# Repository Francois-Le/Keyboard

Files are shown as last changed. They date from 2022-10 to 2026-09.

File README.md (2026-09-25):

Complete custom keyboard with pcb design, 3D printable casing and firmware for a raspberry pi pico. Uses kailh low profile switches.

*Warning:* PCB_v2 may have some design mistake, I can't remember if I fixed them.

The firmware in `code/arduino_keyboard` provides HID keyboard output and an
optional binary USB serial trace. See its README for Arduino Mbed Pico build
instructions.

Open `code/remote/index.html` in desktop Chrome or Edge for the Web Serial
debugger: a vertical input/decision/HID timeline with queue inspection. It works
as a local file or a hosted HTTPS page; **Demo trace** works without hardware.
The remote README describes the protocol, capture export/import and development.

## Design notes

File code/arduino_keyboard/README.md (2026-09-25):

# Keyboard firmware and serial tracing

Target: Raspberry Pi Pico, **Arduino Mbed OS RP2040 Boards** (`arduino:mbed_rp2040:pico`).
The firmware uses the Mbed core's pluggable USB HID and CDC modules on the same
USB connection. It is not intended for the unrelated Earle Philhower RP2040 core.

Build with Arduino IDE or Arduino CLI (Mbed RP2040 core 4.6.0):

```powershell
arduino-cli core install arduino:mbed_rp2040@4.6.0
arduino-cli compile --fqbn arduino:mbed_rp2040:pico code\arduino_keyboard
```

Upload using the Pico's usual Arduino/BOOTSEL workflow. Opening the serial
debugger is optional: HID typing continues without it. Open
`code\remote\index.html` in desktop Chrome or Edge, select the keyboard's serial
port and close any other serial monitor first.

## Trace behavior

`REMOTE_TRACE` in `config.h` is enabled by default. It emits the KBT1 binary
protocol documented in `code\remote\README.md`. The interface is output-only:
there are no parameter-setting commands yet. Do not open it at 1200 baud, which
the Mbed core reserves for entering the bootloader.

- Events cover sampled switch changes, debounce/tap/overlap waits and decisions,
  queue removal, layer masks, I2C recovery attempts and exact HID reports.
- Input timestamps describe software observations, not exact electrical edges.
  HID success is the return value of the USB submission API, not proof that the
  OS/application received a key. A single `HID_OUTPUT` trace frame combines the
  keyboard and media reports, keeping both submission results and durations.
  The actual two USB HID reports are unchanged.
- A 24 KiB, fixed-size ring decouples instrumentation from USB. The loop makes
  at most four nonblocking `send_nb()` attempts per service call, preserving
  partially sent frames. It never waits for a debugger or a slow reader.
- Collection starts when CDC DTR is asserted. Closing the port discards pending
  telemetry. This is live capture, not a persistent pre-connection recorder.
- Reconnect starts a new stream with metadata and a queue checkpoint. Complete
  checkpoints are also attempted every two seconds; insufficient buffer space
  defers the whole checkpoint until space is available.
- Metadata includes the names in `s_layerNames` in `keyConfig.h`, indexed by
  the same masks as `s_keyMaps`. Keep these aligned when changing key maps.
  Names are limited to 24 printable ASCII characters and checked at compile
  time. Metadata and queue records are reserved as one complete batch.
- Trace overflow drops new trace frames, increments the sequence and exposes a
  loss counter. The browser marks reconstruction unknown until a checkpoint.
  This is separate from the existing processing queue's overflow: that behavior
  is unchanged, but an explicit `QUEUE_OVERFLOW` marker now exposes it.
- The UI reconstructs the logical processing queue, not a dump of unused slots
  or deletion markers. Entries retain physical slot numbers and stable IDs.
- Timestamps extend the 32-bit microsecond clock in the main loop. As with other
  polling clock extensions, an entire clock wrap spent blocked (about 71 minutes)
  cannot be recovered. Existing HID sends, I2C operations and tap delays retain
  their existing behavior; the new CDC transmitter does not add blocking waits.

Legacy `DEBUG_LOG`, `I2C_RESET_LOG` and `PERF_LOG` text modes cannot be mixed with
the binary stream. Disable `REMOTE_TRACE` before enabling them.

## Host-side trace checks

With Clang and a working C++ standard library installed:

```powershell
clang++ -std=c++17 -Icode\tests\stubs code\tests\trace_test.cpp -o trace-test.exe
.\trace-test.exe
```

The test compiles the actual trace implementation against a USB stub, including
short/zero writes, CRC framing, timestamp wrap, queue-slot wrap, trace loss and
reconnect. An optional filename argument writes a binary capture for exercising
the browser decoder. This does not replace physical HID + CDC enumeration,
unplug/replug and typing checks on the Pico.

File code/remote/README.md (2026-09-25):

# Keyboard Trace Timeline

Standalone local Web Serial viewer for the custom keyboard KBT1 trace stream. Open `index.html` by double-clicking it, or host the same file over HTTPS. There are no runtime network dependencies, module imports, service workers, framework bundles or telemetry. Only the display-layout preference is saved in browser storage; captures are not stored automatically.

## Build and test

```powershell
cd code\remote
node build.mjs
node --test
```

`src\trace.js`, `src\app.js`, and `src\styles.css` are the classic sources. `index.html` is the tracked generated artifact.

## Connect

1. Use Edge or Chrome with Web Serial support.
2. Open `index.html` locally or from HTTPS.
3. Click **Connect keyboard** and select the serial device.
4. The app opens at `115200` baud and sets DTR `true`.

The app never uses 1200-baud reset and never writes commands to the device. If no valid `HELLO` arrives shortly after opening, the UI warns about wrong/old firmware or port selection. Use **Demo trace** without hardware. Import/demo are disabled while live capture is active to avoid mixing sources.

Trace data can reveal typed keys. Exports are JSON and stay local unless you share them.

The app fits the viewport; the timeline and details panel scroll independently.
The **CHECKPOINT** category contains HELLO metadata and successful queue
snapshots and is unchecked by default. Hidden checkpoints are still processed
and exported, so queue reconstruction remains accurate. Checkpoint errors and
trace-loss warnings stay in **INTERNAL**.
**INTERNAL** shows debounce cancellations, overlap removals and layer changes,
plus faults such as I2C resets, queue overflow and stream errors.
Routine waits, processing, tap/hold decisions, queue removals and connection
boundaries are in **DETAILS**, also unchecked by default. Filtering affects only
display: all events still update the model and remain available in exports.
Older imported captures are reclassified into these categories automatically.
Layer changes use names supplied by firmware metadata, e.g. **Layer changed:
Accent 2**, with the numeric mask still available in the inspector. The name
table is indexed by the effective key-map mask, not by individual held layer
keys: masks 6 and 7 both select Accent 2. Names stay attached to their original
events across reconnects and capture export/import. Older firmware/captures or
incomplete/lost metadata display the numeric mask instead of guessing.
Reflash the firmware to enable layer-name metadata.
All timeline rows have one-line summaries: event/action, relevant IDs or layer,
and time. Checkpoints show the stream ID or pending queue count. Click a row for timestamps, report
bytes, submission results, transitions and queue state. Visible row/column
numbers start at 1; raw protocol coordinates start at 0. Output summaries show
the currently reported pressed keys using the selected **Layout**:
**English (US QWERTY)** or **French (France AZERTY)** (traditional PC layout).
French labels include A/Q, Z/W, M and punctuation/accent keys, and AltGr.
This changes the viewer only, not the firmware or the computer's keyboard layout.
Output shows the translated symbol first, followed by the physical combination
in gray: `OUTPUT { (AltGr, ')`. Shift and French AltGr (including Windows
Ctrl+Alt) are interpreted. The parentheses retain unmodified key labels.
Letters assume Caps Lock off; keypad keys retain their names because Num Lock
is not captured. Shortcuts are labeled `Shortcut`, dead keys `Dead`, and
unsupported modifier levels `Unmapped`. This is a preview of each held key,
not an ordered text stream or confirmation of host input. Dead-key/IME
composition is not inferred. Failed submissions remain visibly marked.

Changing Layout immediately relabels retained/imported events and their inspector
headings. Exported summaries use the selected layout while raw HID bytes remain
unchanged; importing uses your current display preference. English is the initial
default. The selection is remembered for the current site/local-file context when
browser storage is available; otherwise a session-only notice is shown.

### Layout library choice

No new runtime dependency is needed for these two layouts.
[Keyboard Map API](https://wicg.github.io/keyboard-map/#h-keyboard-getlayoutmap)
only exposes unmodified labels, not the Shift/AltGr levels required here.
[simple-keyboard-layouts](https://github.com/hodgef/simple-keyboard-layouts)
provides onscreen keyboard rows rather than a HID/modifier decoder;
[native-keymap](https://github.com/microsoft/node-native-keymap) requires native
Node bindings and cannot run in a standalone browser file.
[hid-io/layouts](https://github.com/hid-io/layouts) is a useful data source if
more layouts are added, but is not a browser text-input engine.

The explicit French levels follow the traditional Windows
[KBDFR shift states](https://kbdlayout.info/KBDfr/shiftstates).
Keeping the small tables in the bundle works offline and permits deterministic
replay using the selected layout, independent of the viewer's current OS layout.

Update the firmware to get one combined keyboard/media trace event per output.
The viewer also accepts the older individual type-5 reports and saved captures.

## KBT1 frame format

Every frame is exactly 48 bytes:

| Offset | Field |
| --- | --- |
| 0..3 | ASCII magic `KBT1` |
| 4 | type |
| 5..7 | reserved, must be zero |
| 8..11 | sequence `uint32LE`, increments for every attempted frame including drops |
| 12..19 | extended device timestamp, microseconds, `uint64LE` |
| 20..45 | 26-byte payload, zero padded |
| 46..47 | CRC16-CCITT-FALSE `uint16LE`, polynomial `0x1021`, init `0xffff`, over bytes 0..45 |

Unsupported `KBTx` versions, CRC errors, garbage, invalid reserved bytes, unknown types, sequence gaps, and malformed payload values are surfaced as timeline errors. Parser errors immediately invalidate queue state.

## Payloads

Offsets below are relative to payload byte 20.

### `1 HELLO`

`boardVersion u8@0`, `rows u8@1`, `cols u8@2`, `overlapEnabled u8@3` (`0/1`), `debounceUs u32@4`, `overlapUs u32@8`, `maxHoldUs u32@12`, `keyPressMs u32@16`, `streamId u32@20`, `layerCount u16@24`.

Sent on start and at periodic 2s checkpoints. Repeated `HELLO` does not erase the prior timeline and does not establish queue contents; only a complete snapshot does.
`layerCount` is zero in older firmware. When nonzero, HELLO is followed by that
many type-13 records (masks 0 through `layerCount - 1`) before SNAPSHOT_BEGIN.
The name table is published only when all records arrive in order without gaps.
The individual name records do not add timeline rows.

### `2 INPUT` and `7 SNAPSHOT_ENTRY`

`id u32@0`, `sampleMicros32 u32@4`, `row u8@8`, `col u8@9`, `pressed u8@10` (`0/1`), `queue slot u8@11`.

Rows/cols are checked after `HELLO`. Queue order is ring order from checkpoints, including wrap (`254,255,0`), not numeric sort.

### `3 REMOVE`

`id u32@0`, `reason u8@4`, `slot u8@5`.

Reasons: `1 processed`, `2 debounce`, `3 tap`, `4 overlap`. Removal must match both id and slot when queue is known.

### `4 DECISION`

`primaryID u32@0`, `relatedID u32@4`, `action u8@8`, `layerMask u8@9`, `interveningCount u8@10`.

Actions: `1 debounceWait`, `2 debounceCancel`, `3 overlapWait`, `4 overlapTap`, `5 tapWait`, `6 tap`, `7 hold(no tap)`, `8 process`, `9 layer`.

### `5 HID`

Legacy/standalone single-report record. Normal keyboard output now uses type 12.

`reportLength u8@0`, `success u8@1` (`0/1`), `sendDurationUs u32@2`, raw report bytes at payload `@6`.

Valid reports are keyboard ID `1` length `9` (`ID, modifier, reserved, six key bytes`) and media ID `3` length `2` (`ID, bitmask`). The UI interprets modifier/key/media state and highlights press/release differences after the first successful report. Success means API submission only, not host receipt.

### `6 SNAPSHOT_BEGIN` / `8 SNAPSHOT_END`

Begin: `count u16@0`, `head u8@2`, `tail u8@3`, `checkpointID u32@4`.

End: `count u16@0`, `checkpointID u32@4`.

Counts must be `<=255`. A snapshot publishes atomically only when begin, exactly `count` entries, and matching end are uninterrupted, ids/slots are unique, and entries follow head/tail wrap order.

### `9 LOSS`, `10 I2C_RESET`, `11 QUEUE_OVERFLOW`

- `LOSS`: cumulative dropped trace frames `u32@0`; queue becomes unknown.
- `I2C_RESET`: `chipIndex u8@0`.
- `QUEUE_OVERFLOW`: `head u8@0`, `tail u8@1`; observer only, queue becomes unknown until checkpoint.

### `12 HID_OUTPUT`

One trace event for one keyboard output update, after both USB reports have
been submitted. USB still receives separate keyboard and media reports.

`keyboardSuccess u8@0`, `mediaSuccess u8@1` (each `0/1`),
`keyboardDurationUs u32@2`, `mediaDurationUs u32@6`,
keyboard report (9 bytes, ID `1`) at `@10`, media report (2 bytes, ID `3`) at `@19`.

Both success flags and durations remain available in the details inspector;
a partial failure is never presented as a successful combined update.
Media bits match the firmware descriptor: next track, previous track, stop,
play/pause, mute, volume up, volume down (bits 0..6).

### `13 LAYER_NAME`

`layerMask u8@0`, `nameLength u8@1`, name bytes at `@2` (1..24 printable ASCII
bytes, no terminator on the wire; unused payload bytes are zero).
The current firmware sends `Base`, `Shift`, `Function`, `Function`, `Accent`,
`Accent`, `Accent 2`, `Accent 2` for masks 0..7. This table is configured next to
`s_keyMaps` in `keyConfig.h`, not duplicated in the viewer.

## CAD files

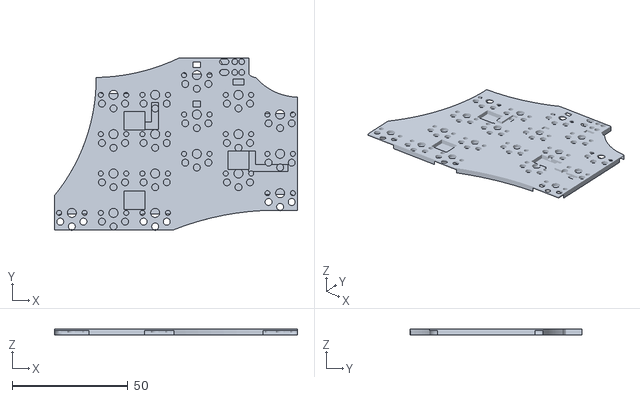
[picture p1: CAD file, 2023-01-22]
casing/enclosure v2-back.stl
105.0 x 74.5 x 2.50

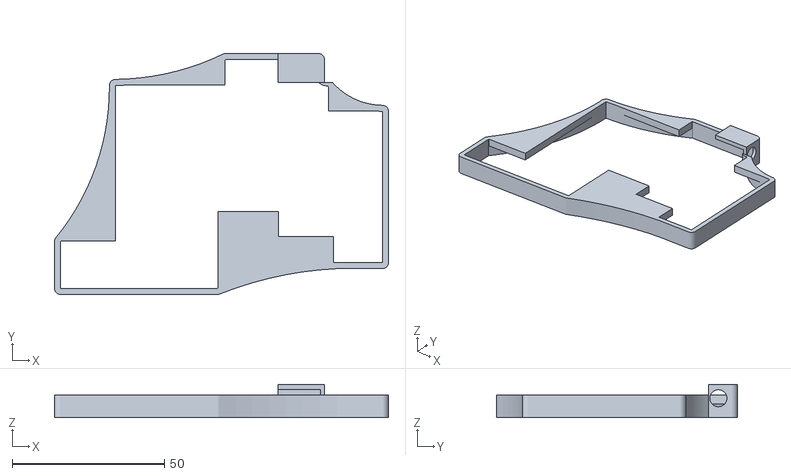
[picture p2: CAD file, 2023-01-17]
casing/enclosure v2-front.stl
109.6 x 79.1 x 10.9

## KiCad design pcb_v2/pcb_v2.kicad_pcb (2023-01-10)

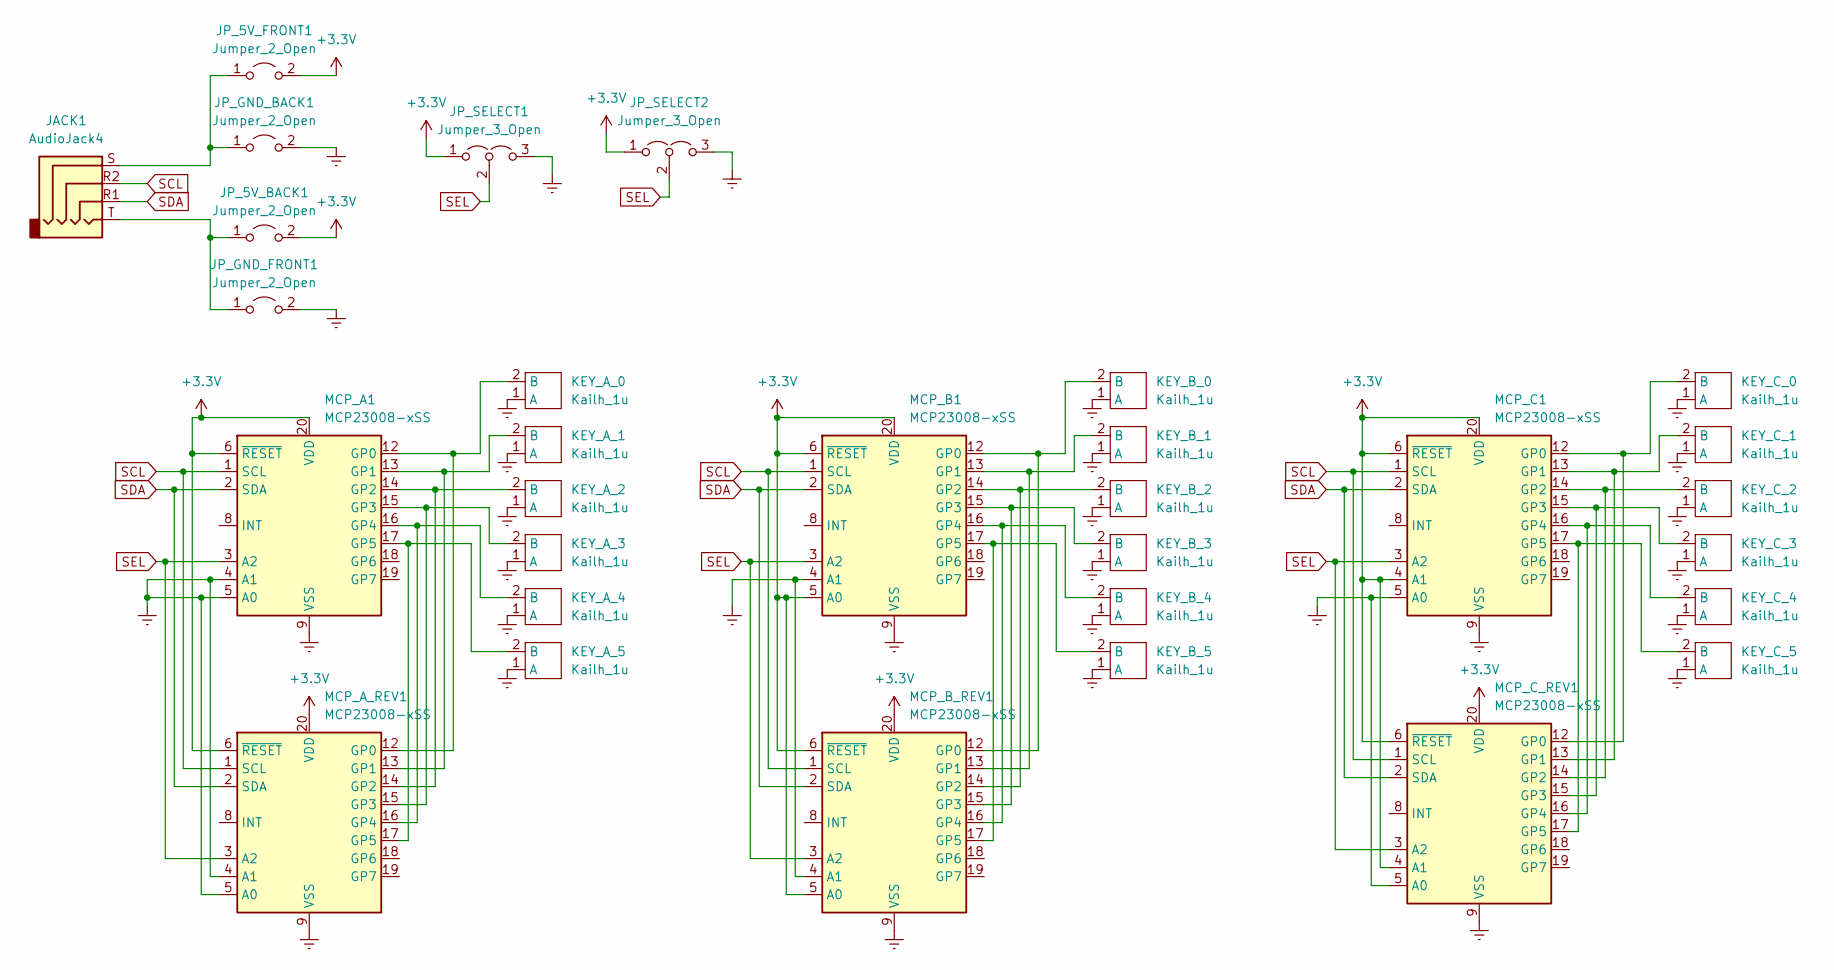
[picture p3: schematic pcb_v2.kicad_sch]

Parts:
JACK1: AudioJack4; TRRS-PJ-320A-no-Fmask-reversible
JP_5V_BACK1, JP_5V_FRONT1: Jumper_2_Open; SolderJumper-2_P1.3mm_Open_Pad1.0x1.5mm
JP_GND_BACK1: Jumper_2_Open; SolderJumper-2_P1.3mm_Open_Pad1.0x1.5mm
JP_GND_FRONT1: Jumper_2_Open; SolderJumper-2_P1.3mm_Open_Pad1.0x1.5mm
JP_SELECT1, JP_SELECT2: Jumper_3_Open; SolderJumper-3_P1.3mm_Open_Pad1.0x1.5mm
KEY_A_0, KEY_A_1, KEY_A_2, KEY_A_3, KEY_A_4, KEY_A_5: Kailh_1u; SW_PG1350_reversible
KEY_B_0, KEY_B_1, KEY_B_2, KEY_B_3, KEY_B_4, KEY_B_5: Kailh_1u; SW_PG1350_reversible
KEY_C_0, KEY_C_1, KEY_C_2, KEY_C_3, KEY_C_4, KEY_C_5: Kailh_1u; SW_PG1350_reversible
MCP_A1: MCP23008-xSS; SSOP-20_5.3x7.2mm_P0.65mm
MCP_A_REV1: MCP23008-xSS; SSOP-20_5.3x7.2mm_P0.65mm
MCP_B1: MCP23008-xSS; SSOP-20_5.3x7.2mm_P0.65mm
MCP_B_REV1: MCP23008-xSS; SSOP-20_5.3x7.2mm_P0.65mm
MCP_C1: MCP23008-xSS; SSOP-20_5.3x7.2mm_P0.65mm
MCP_C_REV1: MCP23008-xSS; SSOP-20_5.3x7.2mm_P0.65mm

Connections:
+3V3: JP_5V_BACK1.2 (B), JP_5V_FRONT1.2 (B), JP_SELECT1.1 (A), JP_SELECT2.1 (A), MCP_A1.6 (~RESET), MCP_A1.20 (VDD), MCP_A_REV1.6 (~RESET), MCP_A_REV1.20 (VDD), MCP_B1.5 (A0), MCP_B1.6 (~RESET), MCP_B1.20 (VDD), MCP_B_REV1.5 (A0), MCP_B_REV1.6 (~RESET), MCP_B_REV1.20 (VDD), MCP_C1.4 (A1), MCP_C1.6 (~RESET), MCP_C1.20 (VDD), MCP_C_REV1.4 (A1), MCP_C_REV1.6 (~RESET), MCP_C_REV1.20 (VDD)
Earth: JP_GND_BACK1.2 (B), JP_GND_FRONT1.2 (B), JP_SELECT1.3 (B), JP_SELECT2.3 (B), KEY_A_0.1 (A), KEY_A_1.1 (A), KEY_A_2.1 (A), KEY_A_3.1 (A), KEY_A_4.1 (A), KEY_A_5.1 (A), KEY_B_0.1 (A), KEY_B_1.1 (A), KEY_B_2.1 (A), KEY_B_3.1 (A), KEY_B_4.1 (A), KEY_B_5.1 (A), KEY_C_0.1 (A), KEY_C_1.1 (A), KEY_C_2.1 (A), KEY_C_3.1 (A), KEY_C_4.1 (A), KEY_C_5.1 (A), MCP_A1.4 (A1), MCP_A1.5 (A0), MCP_A1.9 (VSS), MCP_A_REV1.4 (A1), MCP_A_REV1.5 (A0), MCP_A_REV1.9 (VSS), MCP_B1.4 (A1), MCP_B1.9 (VSS), MCP_B_REV1.4 (A1), MCP_B_REV1.9 (VSS), MCP_C1.5 (A0), MCP_C1.9 (VSS), MCP_C_REV1.5 (A0), MCP_C_REV1.9 (VSS)
unnamed: JACK1.S, JP_5V_FRONT1.1 (A), JP_GND_BACK1.1 (A)
unnamed: JACK1.T, JP_5V_BACK1.1 (A), JP_GND_FRONT1.1 (A)
unnamed: KEY_A_0.2 (B), MCP_A1.12 (GP0), MCP_A_REV1.12 (GP0)
unnamed: KEY_A_1.2 (B), MCP_A1.13 (GP1), MCP_A_REV1.13 (GP1)
unnamed: KEY_A_2.2 (B), MCP_A1.14 (GP2), MCP_A_REV1.14 (GP2)
unnamed: KEY_A_3.2 (B), MCP_A1.15 (GP3), MCP_A_REV1.15 (GP3)
unnamed: KEY_A_4.2 (B), MCP_A1.16 (GP4), MCP_A_REV1.16 (GP4)
unnamed: KEY_A_5.2 (B), MCP_A1.17 (GP5), MCP_A_REV1.17 (GP5)
unnamed: KEY_B_0.2 (B), MCP_B1.12 (GP0), MCP_B_REV1.12 (GP0)
unnamed: KEY_B_1.2 (B), MCP_B1.13 (GP1), MCP_B_REV1.13 (GP1)
unnamed: KEY_B_2.2 (B), MCP_B1.14 (GP2), MCP_B_REV1.14 (GP2)
unnamed: KEY_B_3.2 (B), MCP_B1.15 (GP3), MCP_B_REV1.15 (GP3)
unnamed: KEY_B_4.2 (B), MCP_B1.16 (GP4), MCP_B_REV1.16 (GP4)
unnamed: KEY_B_5.2 (B), MCP_B1.17 (GP5), MCP_B_REV1.17 (GP5)
unnamed: KEY_C_0.2 (B), MCP_C1.12 (GP0), MCP_C_REV1.12 (GP0)
unnamed: KEY_C_1.2 (B), MCP_C1.13 (GP1), MCP_C_REV1.13 (GP1)
unnamed: KEY_C_2.2 (B), MCP_C1.14 (GP2), MCP_C_REV1.14 (GP2)
unnamed: KEY_C_3.2 (B), MCP_C1.15 (GP3), MCP_C_REV1.15 (GP3)
unnamed: KEY_C_4.2 (B), MCP_C1.16 (GP4), MCP_C_REV1.16 (GP4)
unnamed: KEY_C_5.2 (B), MCP_C1.17 (GP5), MCP_C_REV1.17 (GP5)
SCL: JACK1.R2, MCP_A1.1 (SCL), MCP_A_REV1.1 (SCL), MCP_B1.1 (SCL), MCP_B_REV1.1 (SCL), MCP_C1.1 (SCL), MCP_C_REV1.1 (SCL)
SDA: JACK1.R1, MCP_A1.2 (SDA), MCP_A_REV1.2 (SDA), MCP_B1.2 (SDA), MCP_B_REV1.2 (SDA), MCP_C1.2 (SDA), MCP_C_REV1.2 (SDA)
SEL: JP_SELECT1.2 (C), JP_SELECT2.2 (C), MCP_A1.3 (A2), MCP_A_REV1.3 (A2), MCP_B1.3 (A2), MCP_B_REV1.3 (A2), MCP_C1.3 (A2), MCP_C_REV1.3 (A2)

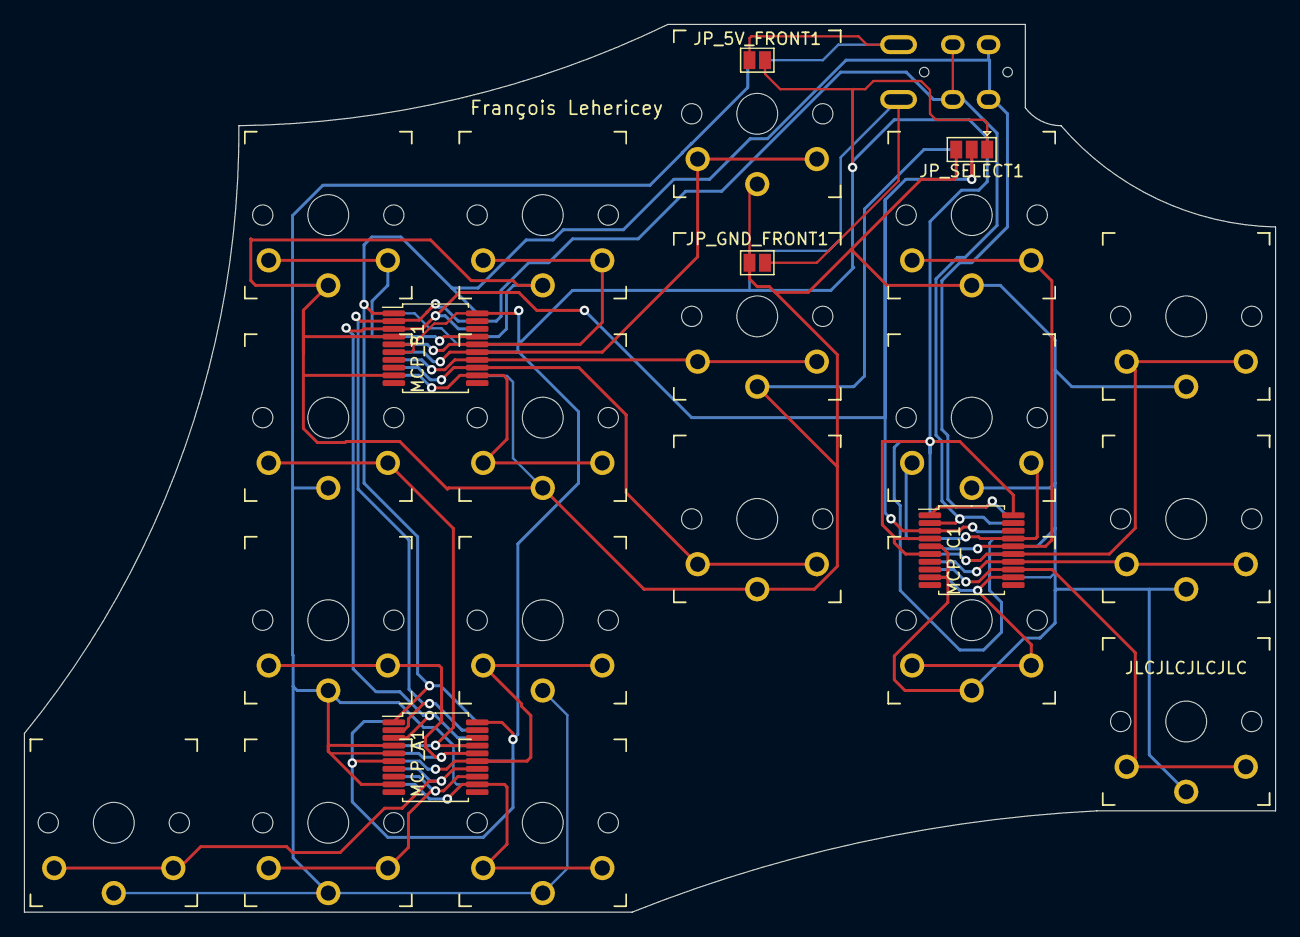
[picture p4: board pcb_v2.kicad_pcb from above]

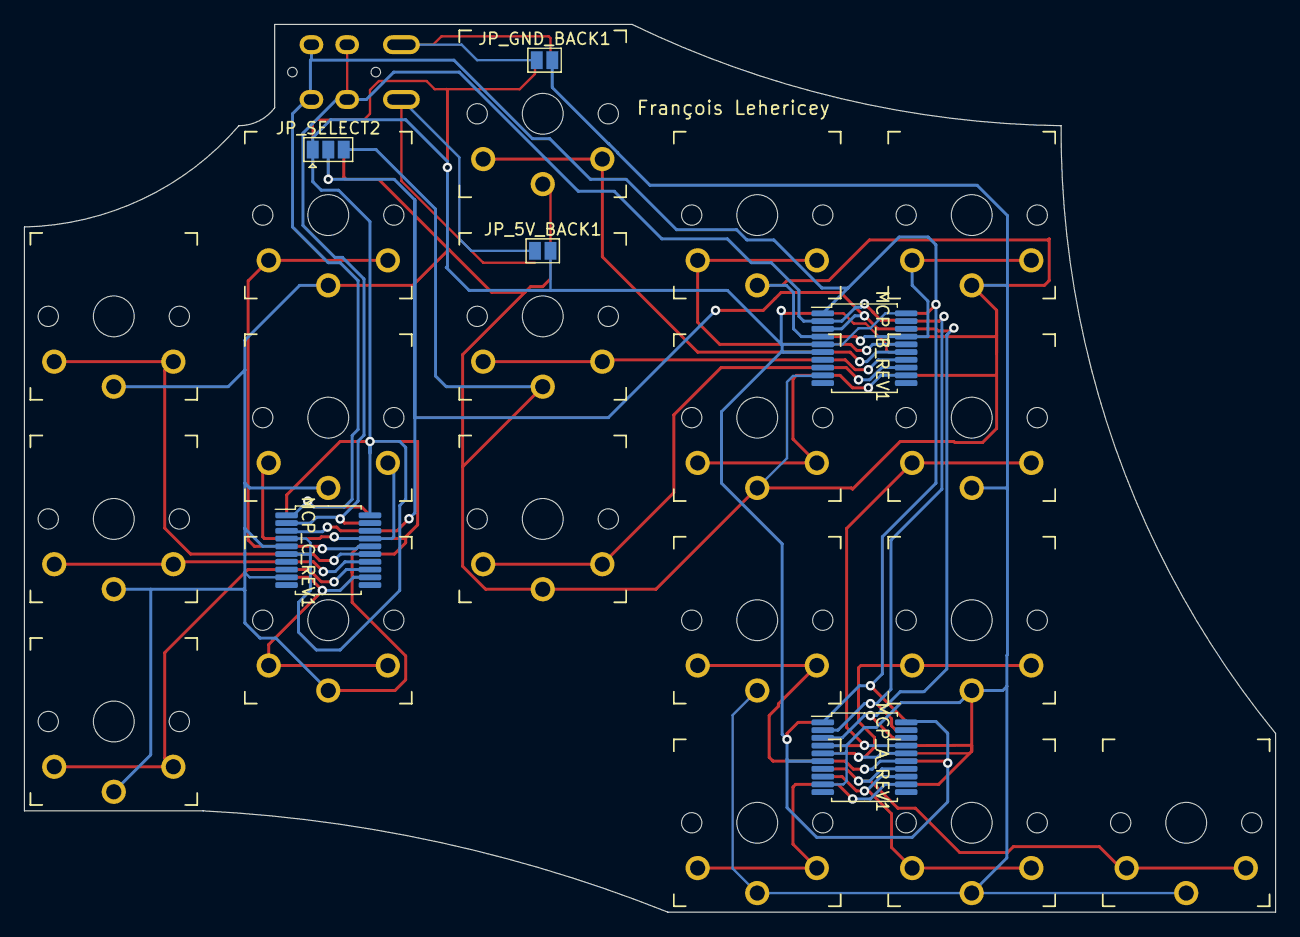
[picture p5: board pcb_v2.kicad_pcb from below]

Board: 2 copper layers, 105.0 x 74.5 mm, 31 parts (6 on the bottom side), 25 nets.

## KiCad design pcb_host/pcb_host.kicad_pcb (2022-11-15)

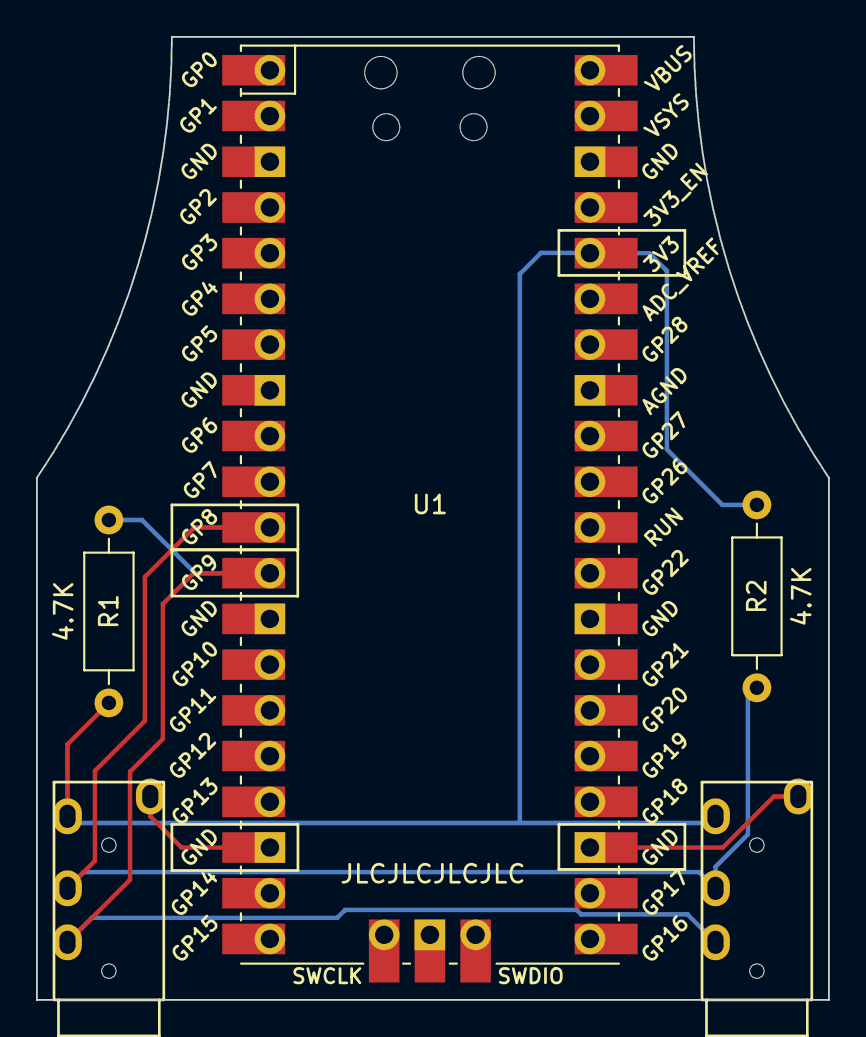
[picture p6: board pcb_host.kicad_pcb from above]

Board: 2 copper layers, 44.0 x 53.5 mm, 5 parts (0 on the bottom side), 5 nets.

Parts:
J1, J2: AudioJack4; TRRS-PJ-320A-no-Fmask
R1, R2: 4.7K; R_Axial_DIN0207_L6.3mm_D2.5mm_P10.16mm_Horizontal
U1: Pico; RPi_Pico_SMD_TH

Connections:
unnamed: J2.S, U1.23 (GND)
unnamed: J1.T, J2.T, R1.1, R2.1, U1.36 (3V3)
unnamed: J1.S, U1.18 (GND)
SCL: J1.R2, J2.R2, R1.2, U1.12 (GPIO9)
SDA: J1.R1, J2.R1, R2.2, U1.11 (GPIO8)

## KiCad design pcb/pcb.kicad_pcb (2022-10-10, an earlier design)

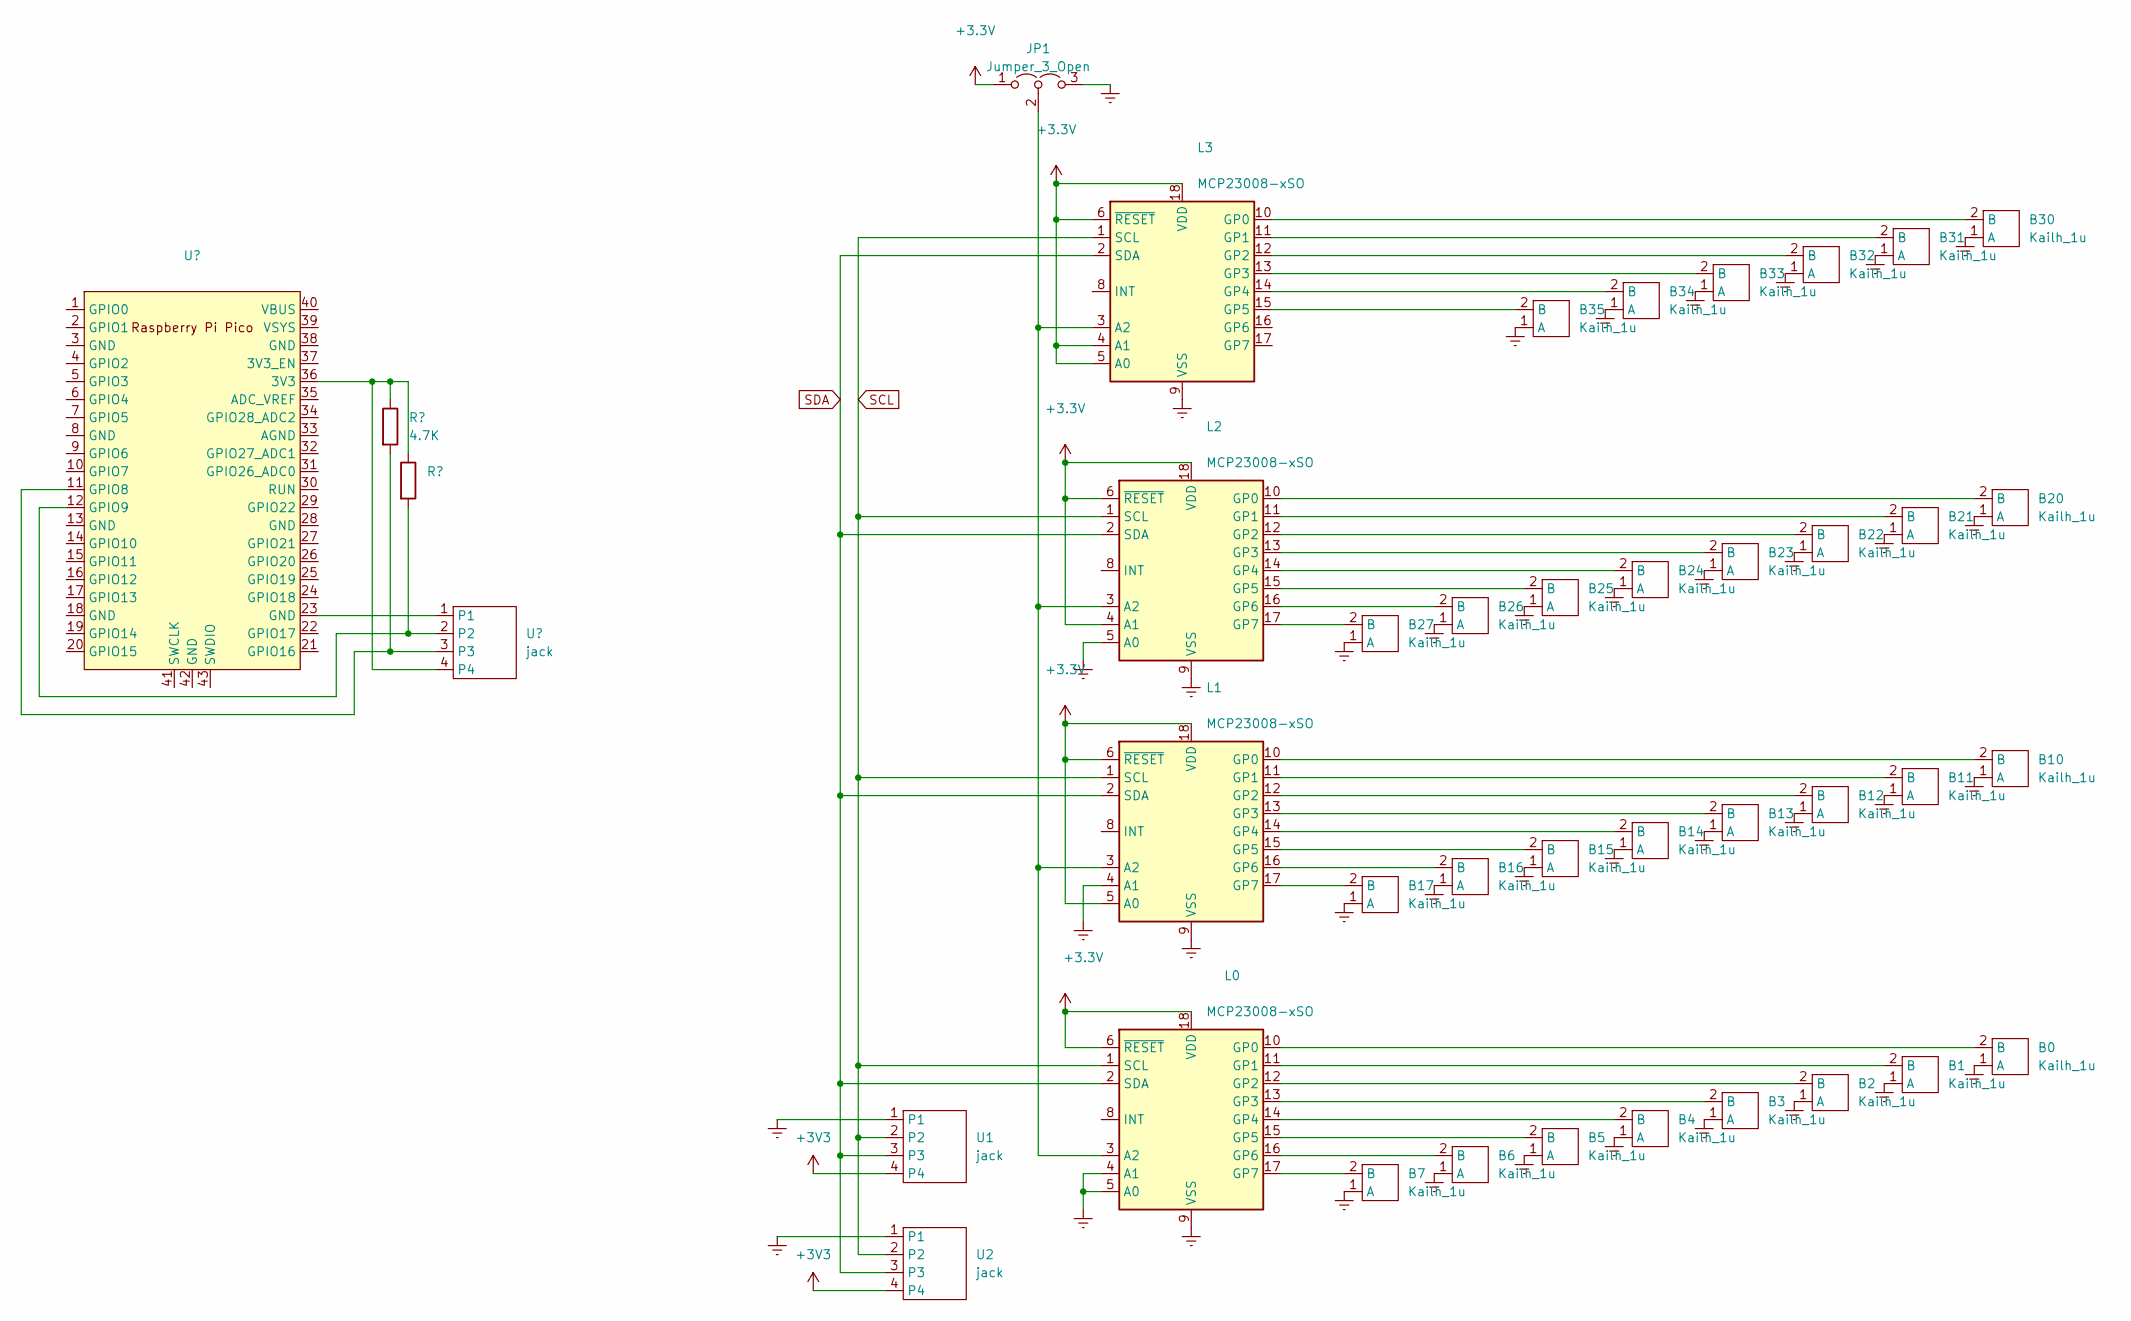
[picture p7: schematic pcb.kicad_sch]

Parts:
B0, B1, B2, B3, B4, B5, B6, B7, B10, B11, B12, B13, B14, B15, B16, B17, B20, B21, B22, B23, B24, B25, B26, B27, B30, B31, B32, B33, B34, B35: Kailh_1u; SW_Kailh_Choc_V1_1.00u
JP1: Jumper_3_Open; SolderJumper-3_P1.3mm_Open_RoundedPad1.0x1.5mm
L0, L1, L2, L3: MCP23008-xSO; SOIC-18W_7.5x11.6mm_P1.27mm
U1, U2: jack

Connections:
Earth: B0.1 (A), B1.1 (A), B2.1 (A), B3.1 (A), B4.1 (A), B5.1 (A), B6.1 (A), B7.1 (A), B10.1 (A), B11.1 (A), B12.1 (A), B13.1 (A), B14.1 (A), B15.1 (A), B16.1 (A), B17.1 (A), B20.1 (A), B21.1 (A), B22.1 (A), B23.1 (A), B24.1 (A), B25.1 (A), B26.1 (A), B27.1 (A), B30.1 (A), B31.1 (A), B32.1 (A), B33.1 (A), B34.1 (A), B35.1 (A), JP1.3 (B), L0.4 (A1), L0.5 (A0), L0.9 (VSS), L1.4 (A1), L1.9 (VSS), L2.5 (A0), L2.9 (VSS), L3.9 (VSS), U1.1, U2.1; also elsewhere on the board
unnamed: B0.2 (B), L0.10 (GP0)
unnamed: B1.2 (B), L0.11 (GP1)
unnamed: B2.2 (B), L0.12 (GP2)
unnamed: B3.2 (B), L0.13 (GP3)
unnamed: B4.2 (B), L0.14 (GP4)
unnamed: B5.2 (B), L0.15 (GP5)
unnamed: B6.2 (B), L0.16 (GP6)
unnamed: B7.2 (B), L0.17 (GP7)
unnamed: B10.2 (B), L1.10 (GP0)
unnamed: B11.2 (B), L1.11 (GP1)
unnamed: B12.2 (B), L1.12 (GP2)
unnamed: B13.2 (B), L1.13 (GP3)
unnamed: B14.2 (B), L1.14 (GP4)
unnamed: B15.2 (B), L1.15 (GP5)
unnamed: B16.2 (B), L1.16 (GP6)
unnamed: B17.2 (B), L1.17 (GP7)
unnamed: B20.2 (B), L2.10 (GP0)
unnamed: B21.2 (B), L2.11 (GP1)
unnamed: B22.2 (B), L2.12 (GP2)
unnamed: B23.2 (B), L2.13 (GP3)
unnamed: B24.2 (B), L2.14 (GP4)
unnamed: B25.2 (B), L2.15 (GP5)
unnamed: B26.2 (B), L2.16 (GP6)
unnamed: B27.2 (B), L2.17 (GP7)
unnamed: B30.2 (B), L3.10 (GP0)
unnamed: B31.2 (B), L3.11 (GP1)
unnamed: B32.2 (B), L3.12 (GP2)
unnamed: B33.2 (B), L3.13 (GP3)
unnamed: B34.2 (B), L3.14 (GP4)
unnamed: B35.2 (B), L3.15 (GP5)
unnamed 31: JP1.2 (C), L0.3 (A2), L1.3 (A2), L2.3 (A2), L3.3 (A2); also elsewhere on the board
SCL: L0.1 (SCL), L1.1 (SCL), L2.1 (SCL), L3.1 (SCL), U1.2, U2.2
SDA: L0.2 (SDA), L1.2 (SDA), L2.2 (SDA), L3.2 (SDA), U1.3, U2.3

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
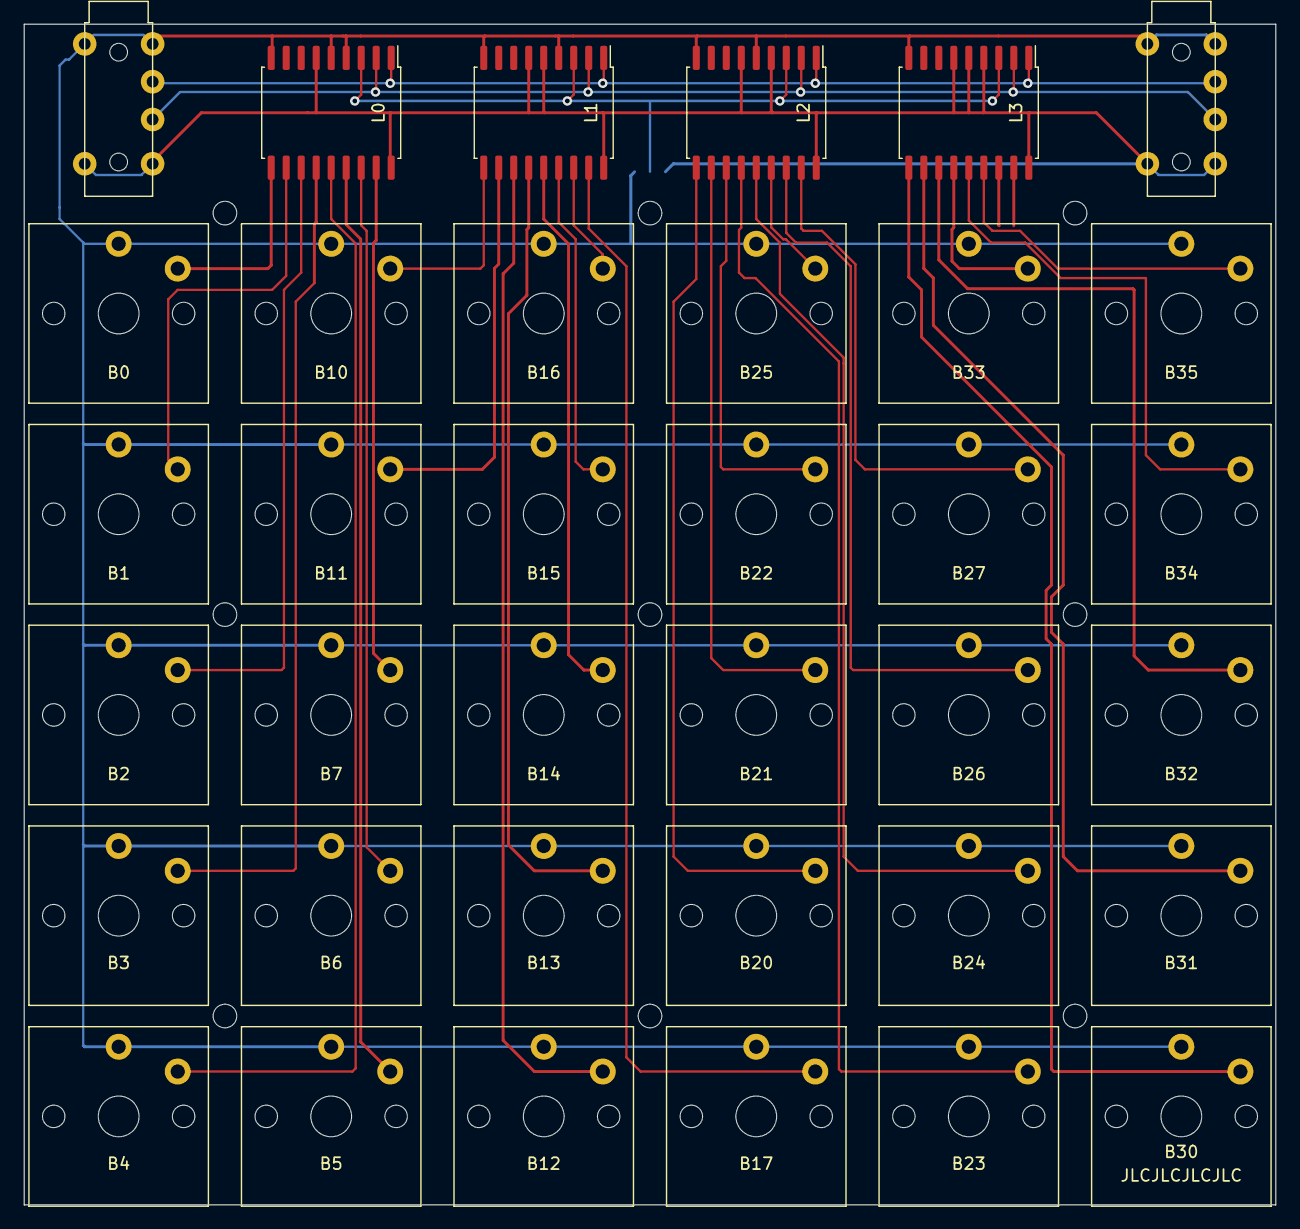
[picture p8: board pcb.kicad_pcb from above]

Board: 2 copper layers, 106.0 x 100.0 mm, 37 parts (1 on the bottom side), 35 nets.

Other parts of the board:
Left/right selection: Jumper_3_Open; SolderJumper-3_P1.3mm_Open_RoundedPad1.0x1.5mm

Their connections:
Earth: Left/right selection.3 (B); also elsewhere on the board
unnamed 31: Left/right selection.2 (C); also elsewhere on the board

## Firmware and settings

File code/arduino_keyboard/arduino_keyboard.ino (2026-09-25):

#include "mbed.h"
#include "config.h"
#include "input.h"
#include "PluggableUSBHID.h"
#include "Keyboard.h"
#include "KeyConfig.h"
#include "event.h"
#include "overlap.h"
#include "trace.h"



class LayerTracker {
public:
  inline void delta(LayerBit i, int8_t d) {
    if (i > 0) {
      m_count[i - 1] += d;

      // Update mask.
      m_mask = 0;
      for (uint8_t i = 0, p = 1; i < 8; ++i, p = p << 1) {
        m_mask = m_mask | (m_count[i] > 0 ? p : 0);
      }
    }
  }

  inline uint8_t mask() {
    return m_mask;
  }

private:
  int8_t m_count[8] = { 0, 0, 0, 0, 0, 0, 0, 0 };
  uint8_t m_mask = 0;
};

/// The queue of input event that are yet to be processed.
EventQueue s_events;
uint32_t s_nextEventId = 0;

void removeFront(Trace::Removal reason) {
  Trace::removed(s_events.peek(), s_events.begin().m_index, reason);
  s_events.popFront();
}

void removeQueued(EventQueue::Iterator it, Trace::Removal reason) {
  Trace::removed(s_events[it], it.m_index, reason);
  s_events.remove(it);
}

/// For each switch on the physical keyboard, track if that switch is currently pressed.
/// Instead of being a bool, we use a counter where "count = 0" mean the switch is not pressed and "count > 0" mean the switch is pressed. We do that so we can do some tricks where we force enable some of the switches momentarely by adding 1 without having to worry about if the switch was already pressed.
uint8_t s_currentPressCount[NUM_LINES][NUM_COLUMNS];

/// Track what layer is currently active
LayerTracker s_layerTracker;

/// Additional key that is forced to be in the output even if the switch is causing that key to be held. This is reset on layer changes.
Key s_forcedKey = Key::NONE;

/// Add 'keys' to the output.
inline void addK(const K& keys) {
  if (keys.m_key0 != Key::NONE) KeyboardOutput::add(keys.m_key0);
  if (keys.m_key1 != Key::NONE) KeyboardOutput::add(keys.m_key1);
  if (keys.m_mediaKey != MediaKey::NONE) KeyboardOutput::add(keys.m_mediaKey);
}

/// Send all the key pressed to the USB bus given the current state of the keyboard.
void sendCurrentKeyPress();
void sendCurrentKeyPress() {
  // Start by resetting the output.
  KeyboardOutput::releaseAll();

  // Get the switch to key mapping for the current active layer.
  K(*currentLayer)
  [12] = s_keyMaps[s_layerTracker.mask()];
  debugPrint("\tLayer mask: ");
  debugPrintln(s_layerTracker.mask());

  // Add the key associated to every active switch.
  for (int line = 0; line < NUM_LINES; ++line) {
    for (int column = 0; column < NUM_COLUMNS; ++column) {
      if (s_currentPressCount[line][column] > 0) {
        K key = currentLayer[line][column];
        addK(key);
      }
    }
  }

  // Add any key that are currently forced held.
  if (s_forcedKey != Key::NONE) {
    addK(s_forcedKey);
  }

  // HACK: If layer 1 is enabled and no key is currently pressed, we press shift. This is because physical shift key is associated to a layer, but if we are not pressing any key on that layer we want shift to be pressed.
  // TODO: improve this code to be more generic.
  if (!KeyboardOutput::isAnyKeyPressed() && s_layerTracker.mask() == 1) {
    addK(Key::SHIFT);
    debugPrintln("\tAdding shift");
  }

  // Send to the USB bus.
  KeyboardOutput::send();
}



void setup() {
  Trace::begin(s_layerNames, LAYER_COUNT);
#if ANY_LOG
  Serial.begin(9600);
#endif

  Input::init();

  for (int line = 0; line < NUM_LINES; ++line) {
    for (int column = 0; column < NUM_COLUMNS; ++column) {
      s_currentPressCount[line][column] = 0;
    }
  }
}

#if PERF_LOG
unsigned long perf_min = -1;
unsigned long perf_max = 0;
unsigned long perf_total = 0;
int perf_count = 0;
static const int perf_countTotal = 1000;
#endif

void loop() {
  Trace::service(s_events);
#if PERF_LOG
  unsigned long perf_start = micros();
#endif

  // We refresh the input.
  Input::step();

  // We add an event in the event queue for each key that have changed state.
  ON_DEBUG(bool anyNewEvent = false);
  for (int line = 0; line < NUM_LINES; ++line) {
    for (int column = 0; column < NUM_COLUMNS; ++column) {

      if (Input::hasChanged(line, column)) {
        const uint8_t slot = s_events.end().m_index;
        if (uint8_t(slot + 1) == s_events.begin().m_index) {
          // Observe the existing queue overflow; do not change input processing.
          Trace::queueOverflow(s_events.begin().m_index, slot);
        }
        Event& event = s_events.emplaceBack();
        event.m_pos = Pos{ line, column };
        event.m_isPressed = Input::isPressed(line, column);
        event.m_time = micros();
        event.m_id = ++s_nextEventId;
        Trace::input(event, slot);

        ON_DEBUG(anyNewEvent = true);
      }
    }
  }

#if DEBUG_LOG
  if (anyNewEvent) {
    debugPrintln("new events added to queue:");
    s_events.print("\t");
  }
#endif

  // Now we are going to process the every event in the queue that we can.
  unsigned long current = micros();
  while (!s_events.isEmpty()) {
    const Event& event = s_events.peek();

    // Debouncing.
    // The way we do debouncing is we wait any event to be older than DEBOUNCE_TIME before processing to check if we can cancel it.
    {
      // If the event is not old enough, we have to wait a bit and pull the switches to check if we need to debounce.
      if (current - event.m_time < DEBOUNCE_TIME) {
        Trace::decision(event, Trace::Action::DEBOUNCE_WAIT);
        break;
      }

      // We look at future event and see if we have an event in the queue that match this key with an opposite state withing the debouncing time frame.
      bool debounced = false;
      for (EventQueue::Iterator it : s_events) {
        // We are outside the debouncing time frame, we can stop looking for events.
        if (s_events[it].m_time - event.m_time > DEBOUNCE_TIME) {
          break;
        }

        // If the event is for the same key and with the opposite state, we have can debounce.
        if (s_events[it].m_pos == event.m_pos && s_events[it].m_isPressed != event.m_isPressed) {
          debugPrint("Cancel key\n");

          // We remove the current event and the opposite one.
          Trace::decision(event, Trace::Action::DEBOUNCE_CANCEL, s_events[it].m_id);
          removeFront(Trace::Removal::DEBOUNCE);
          removeQueued(it, Trace::Removal::DEBOUNCE);
          debounced = true;
          break;
        }
      }

#if DEBUG_LOG
      if (debounced) {
        debugPrintln("Debounced a key, event queue:");
        s_events.print("\t");
      }
#endif

      // We debounced the current event, go to the next event in the main event processing loop.
      if (debounced) continue;
    }

    // Overlap removal.
    // We do this after debouncing so that the decision is taken on real events rather than on switch bounces, and before the "on release" handling since we are correcting a case that it gets wrong.
#if OVERLAP_REMOVAL
    if (overlapRemoval[event.m_pos.m_line][event.m_pos.m_column] && event.m_isPressed) {
      // Scan the queue after the current press, looking for its release and counting how many other keys were pressed in the meantime.
      OverlapScan scan;
      for (EventQueue::Iterator it = s_events.next(s_events.begin()); it != s_events.end(); ++it) {
        const Event& other = s_events[it];

        if (other.m_pos == event.m_pos) {
          if (!other.m_isPressed) {
            scan.m_foundRelease = true;
            scan.m_releaseTime = other.m_time;
            scan.m_releaseIt = it;
            break;
          }
          continue;
        }

        if (other.m_isPressed) {
          if (scan.m_interveningPressCount == 0) scan.m_firstInterveningPressTime = other.m_time;
          // Saturate so that a long chord cannot wrap the counter back to an accepted value.
          if (scan.m_interveningPressCount < 255) scan.m_interveningPressCount++;
        }
      }

      const OverlapAction action = evaluateOverlap(event, scan, current);

      // We can't tell yet whether this is a tap or a layer hold, poll for more events.
      if (action == OverlapAction::WAIT) {
        Trace::decision(event, Trace::Action::OVERLAP_WAIT, 0, s_layerTracker.mask(), scan.m_interveningPressCount);
        break;
      }

      if (action == OverlapAction::EMIT_TAP) {
        Trace::decision(event, Trace::Action::OVERLAP_TAP, s_events[scan.m_releaseIt].m_id, s_layerTracker.mask(), scan.m_interveningPressCount);
        debugPrintln("Overlap removal: emit tap");

        // Emit the tap without ever activating the layer, so the key that was pressed in between is
        // resolved on the current layer rather than on the one this key would have selected.
        s_currentPressCount[event.m_pos.m_line][event.m_pos.m_column]++;
        sendCurrentKeyPress();

        delay(KEY_PRESS_LENGTH);  // milliseconds

        s_currentPressCount[event.m_pos.m_line][event.m_pos.m_column]--;
        sendCurrentKeyPress();

        // Drop this key's press and release, leaving every other event untouched.
        removeFront(Trace::Removal::OVERLAP);
        removeQueued(scan.m_releaseIt, Trace::Removal::OVERLAP);

#if DEBUG_LOG
        debugPrintln("Removed an overlap, event queue:");
        s_events.print("\t");
#endif
        continue;
      }
    }
#endif

    // We process "on release" key presses.
    // "on release" key presses are key that trigger an output if they when they are relased if:
    //   - They were released within MAX_HOLD_TIME of being pressed
    //   - No other key was pressed in between, but other key release are acceptable.
    // Typically this is for keys that are associated with layer changes, but output a character when being tapped.
    if (onRelease[event.m_pos.m_line][event.m_pos.m_column] && event.m_isPressed) {
      // We have a key press for a "on release" key.

      // Look up if we can find the event for releasing the current key.
      bool foundRelease = false;
      EventQueue::Iterator releaseIndex;
      // And look if we pressed another key.
      bool foundAnotherPress = false;
      for (EventQueue::Iterator it = s_events.next(s_events.begin()); it != s_events.end(); ++it) {
        if (s_events[it].m_pos == event.m_pos && !s_events[it].m_isPressed) {
          foundRelease = true;
          releaseIndex = it;
          break;
        }

        if (s_events[it].m_pos != event.m_pos && s_events[it].m_isPressed) {
          foundAnotherPress = true;
          break;
        }
      }

      if (!foundAnotherPress) {
        if (foundRelease) {
          // We found the release event, and there was no press in between. If the two events are within the MAX_HOLD_TIME, we execute the "on release" behavior
          if (s_events[releaseIndex].m_time - event.m_time < MAX_HOLD_TIME) {
            Trace::decision(event, Trace::Action::TAP, s_events[releaseIndex].m_id, s_layerTracker.mask());
            debugPrintln("Press and release key");

            s_currentPressCount[event.m_pos.m_line][event.m_pos.m_column]++;
            sendCurrentKeyPress();

            delay(KEY_PRESS_LENGTH);  // milliseconds

            s_currentPressCount[event.m_pos.m_line][event.m_pos.m_column]--;
            sendCurrentKeyPress();
          } else {
            Trace::decision(event, Trace::Action::HOLD, s_events[releaseIndex].m_id, s_layerTracker.mask());
          }

          // Remove the two events from the queue and go to the next event.
          removeFront(Trace::Removal::TAP);
          removeQueued(releaseIndex, Trace::Removal::TAP);
          continue;
        } else {
          // We have not found any other key press and we don't have found the release event, we don't know what to do yet, pull for more events.
          Trace::decision(event, Trace::Action::TAP_WAIT);
          break;
        }
      } else {
        // Another key was pressed before we released the current one. We don't execute the "on release" behavior, continue execution normally.
      }
    }

#if DEBUG_LOG
    debugPrint("processing event ");
    debugPrint(s_events.begin().m_index);
    debugPrint(" ");
    event.print();
    debugPrintln();
#endif

    Trace::decision(event, Trace::Action::PROCESS, 0, s_layerTracker.mask());
    // Update the press count for that key.
    uint8_t& pressCount = s_currentPressCount[event.m_pos.m_line][event.m_pos.m_column];
    if (event.m_isPressed) {
      pressCount++;
    } else {
      if (pressCount > 0) pressCount--;
    }

    // If this key has a "forced key" associated wit it, we grab it.
    {
      K(*currentLayer)
      [12] = s_keyMaps[s_layerTracker.mask()];
      Key forced = currentLayer[event.m_pos.m_line][event.m_pos.m_column].m_forcedKey;
      if (forced != Key::NONE) {
        s_forcedKey = forced;
      }
    }

    // Update the the layer (if any change).
    LayerBit layer = s_layerKeys[event.m_pos.m_line][event.m_pos.m_column];
    if (layer != LAYER_NONE) {
      s_layerTracker.delta(layer, event.m_isPressed ? +1 : -1);
      Trace::decision(event, Trace::Action::LAYER, 0, s_layerTracker.mask());

      // Reset button presses when layer change.
      for (int line = 0; line < NUM_LINES; ++line) {
        for (int column = 0; column < NUM_COLUMNS; ++column) {
          if (immuneToReset[line][column]) continue;  // Except key that are immune to reset.
          s_currentPressCount[line][column] = 0;
        }
      }

      // Reset the forced key.
      s_forcedKey = Key::NONE;
    }

#ifdef DEBUG_LOG
    debugPrintln("Current press count:");
    for (int line = 0; line < NUM_LINES; ++line) {
      debugPrint("\t");
      for (int column = 0; column < NUM_COLUMNS; ++column) {
        if (column == 6) debugPrint(" ");
        debugPrint(s_currentPressCount[line][column]);
      }
      debugPrintln();
    }
#endif

    // Output the current state of key pressed to the USB host.
    debugPrintln("Send event:");
    sendCurrentKeyPress();


    removeFront(Trace::Removal::PROCESSED);
  }

#if PERF_LOG
  unsigned long total = micros() - perf_start;

  perf_min = min(perf_min, total);
  perf_max = max(perf_max, total);
  perf_total += total;
  perf_count++;
  if (perf_count == perf_countTotal) {
    unsigned long avg = perf_total / perf_countTotal;
    Serial.print("pulling perf min=");
    Serial.print(perf_min);
    Serial.print("us max=");
    Serial.print(perf_max);
    Serial.print("us avg=");
    Serial.print(avg);
    Serial.println("us");

    perf_min = -1;
    perf_max = 0;
    perf_total = 0;
    perf_count = 0;
  }
#endif
}

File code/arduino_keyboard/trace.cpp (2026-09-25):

#include "trace.h"

#if REMOTE_TRACE
#include <Arduino.h>
#include "USB/PluggableUSBSerial.h"
#include <string.h>

namespace {
constexpr uint16_t FRAME_SIZE = 48;
constexpr uint16_t CAPACITY = 512;
constexpr uint32_t CHECKPOINT_INTERVAL_US = 2000000;
uint8_t frames[CAPACITY][FRAME_SIZE];
static_assert(sizeof(frames) == 24576, "Trace ring RAM budget changed");
uint16_t head = 0, size = 0, offset = 0;
uint32_t sequence = 0, dropped = 0, reportedDropped = 0, stream = 0;
uint32_t lastMicros = 0, checkpointTime = 0, checkpointId = 0;
uint64_t elapsed = 0;
bool connected = false;
uint32_t waitId = 0, waitRelated = 0;
uint8_t waitAction = 0;
const Trace::LayerName* layerNames = nullptr;
uint16_t layerCount = 0;

enum class Type : uint8_t {
  HELLO = 1, INPUT, REMOVE, DECISION, HID,
  SNAPSHOT_BEGIN, SNAPSHOT_ENTRY, SNAPSHOT_END, LOSS, I2C_RESET, QUEUE_OVERFLOW, HID_OUTPUT, LAYER_NAME
};

uint64_t now() {
  const uint32_t current = micros();
  elapsed += uint32_t(current - lastMicros);
  lastMicros = current;
  return elapsed;
}

void put16(uint8_t* out, uint16_t value) {
  out[0] = value;
  out[1] = value >> 8;
}

void put32(uint8_t* out, uint32_t value) {
  for (uint8_t i = 0; i < 4; ++i) out[i] = value >> (8 * i);
}

void emit(Type type, const uint8_t* payload, uint64_t time) {
  if (!connected) return;
  const uint32_t seq = ++sequence;
  if (size == CAPACITY) {
    ++dropped;
    return;
  }
  uint8_t* frame = frames[(head + size) % CAPACITY];
  memset(frame, 0, FRAME_SIZE);
  memcpy(frame, "KBT1", 4);
  frame[4] = uint8_t(type);
  put32(frame + 8, seq);
  put32(frame + 12, uint32_t(time));
  put32(frame + 16, uint32_t(time >> 32));
  memcpy(frame + 20, payload, 26);
  uint16_t crc = 0xffff;
  for (uint8_t i = 0; i < FRAME_SIZE - 2; ++i) {
    crc ^= uint16_t(frame[i]) << 8;
    for (uint8_t bit = 0; bit < 8; ++bit) {
      crc = (crc & 0x8000) ? (crc << 1) ^ 0x1021 : crc << 1;
    }
  }
  put16(frame + FRAME_SIZE - 2, crc);
  ++size;
}

void entry(Type type, const Event& event, uint8_t slot, uint64_t time) {
  uint8_t payload[26] = {};
  put32(payload, event.m_id);
  put32(payload + 4, uint32_t(event.m_time));
  payload[8] = event.m_pos.m_line;
  payload[9] = event.m_pos.m_column;
  payload[10] = event.m_isPressed;
  payload[11] = slot;
  emit(type, payload, time);
}

void drain() {
  // The Mbed Serial.write() is blocking. send_nb() copies only what fits.
  // Bound USB work per loop, retaining an unsent frame suffix for the next loop.
  for (uint8_t attempt = 0; attempt < 4 && size; ++attempt) {
    uint32_t actual = 0;
    _SerialUSB.send_nb(frames[head] + offset, FRAME_SIZE - offset, &actual);
    if (!actual) break;
    offset += actual;
    if (offset == FRAME_SIZE) {
      offset = 0;
      head = (head + 1) % CAPACITY;
      --size;
    }
  }
}

bool checkpoint(EventQueue& queue, uint64_t time) {
  uint16_t count = 0;
  for (auto it = queue.begin(); it != queue.end(); it = queue.next(it)) ++count;
  // This runs only on the scan thread. Reserve the entire batch before emitting
  // anything, so a slow reader cannot produce a partial logical checkpoint.
  if (CAPACITY - size < count + 3 + layerCount) return false;

  uint8_t hello[26] = {};
  hello[0] = VERSION;
  hello[1] = NUM_LINES;
  hello[2] = NUM_COLUMNS;
  hello[3] = OVERLAP_REMOVAL;
  put32(hello + 4, DEBOUNCE_TIME);
  put32(hello + 8, OVERLAP_REMOVAL_TIME);
  put32(hello + 12, MAX_HOLD_TIME);
  put32(hello + 16, KEY_PRESS_LENGTH);
  put32(hello + 20, stream);
  put16(hello + 24, layerCount);
  emit(Type::HELLO, hello, time);
  for (uint16_t mask = 0; mask < layerCount; ++mask) {
    uint8_t payload[26] = {};
    payload[0] = mask;
    payload[1] = strlen(layerNames[mask].text);
    memcpy(payload + 2, layerNames[mask].text, payload[1]);
    emit(Type::LAYER_NAME, payload, time);
  }

  uint8_t boundary[26] = {};
  put16(boundary, count);
  boundary[2] = queue.begin().m_index;
  boundary[3] = queue.end().m_index;
  put32(boundary + 4, ++checkpointId);
  emit(Type::SNAPSHOT_BEGIN, boundary, time);
  for (auto it = queue.begin(); it != queue.end(); it = queue.next(it)) {
    entry(Type::SNAPSHOT_ENTRY, queue[it], it.m_index, time);
  }
  emit(Type::SNAPSHOT_END, boundary, time);
  return true;
}
}

void Trace::begin(const LayerName* layers, uint16_t count) {
  layerNames = layers;
  layerCount = count;
  _SerialUSB.begin(115200);
  now();
}

void Trace::service(EventQueue& queue) {
  const uint64_t time = now();
  // Avoid USBSerial::operator bool(): it calls delay(1).
  if (!_SerialUSB.connected()) {
    connected = false;
    size = head = offset = 0;
    return;
  }
  if (!connected) {
    connected = true;
    ++stream;
    sequence = dropped = reportedDropped = 0;
    size = head = offset = 0;
    waitId = waitRelated = waitAction = 0;
    checkpoint(queue, time);
    checkpointTime = uint32_t(time);
  }
  drain();
  if (dropped != reportedDropped && size < CAPACITY) {
    uint8_t payload[26] = {};
    put32(payload, dropped);
    emit(Type::LOSS, payload, now());
    reportedDropped = dropped;
  }
  if (uint32_t(time - checkpointTime) >= CHECKPOINT_INTERVAL_US && checkpoint(queue, now())) {
    checkpointTime = uint32_t(time);
  }
}

void Trace::input(const Event& event, uint8_t slot) {
  if (connected) entry(Type::INPUT, event, slot, now());
}

void Trace::removed(const Event& event, uint8_t slot, Removal reason) {
  if (!connected) return;
  uint8_t payload[26] = {};
  put32(payload, event.m_id);
  payload[4] = uint8_t(reason);
  payload[5] = slot;
  emit(Type::REMOVE, payload, now());
  waitAction = 0;
}

void Trace::decision(const Event& event, Action action, uint32_t related, uint8_t layer, uint8_t count) {
  if (!connected) return;
  const bool waiting = action == Action::DEBOUNCE_WAIT || action == Action::OVERLAP_WAIT || action == Action::TAP_WAIT;
  if (waiting && waitId == event.m_id && waitRelated == related && waitAction == uint8_t(action)) return;
  waitId = event.m_id;
  waitRelated = related;
  waitAction = waiting ? uint8_t(action) : 0;
  uint8_t payload[26] = {};
  put32(payload, event.m_id);
  put32(payload + 4, related);
  payload[8] = uint8_t(action);
  payload[9] = layer;
  payload[10] = count;
  emit(Type::DECISION, payload, now());
}

void Trace::hid(const uint8_t* report, uint8_t length, bool success, uint32_t duration) {
  if (!connected) return;
  uint8_t payload[26] = {};
  payload[0] = length;
  payload[1] = success;
  put32(payload + 2, duration);
  memcpy(payload + 6, report, length);
  emit(Type::HID, payload, now());
}
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

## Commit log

2022-10-10 Import to git
    [Key layout.xlsx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]
2022-10-24 update key layout
    [Key layout.xlsx]
2022-10-29 update layout
    [Key layout.xlsx]
2022-11-04 Swap location of square and curly brackets
    [Key layout.xlsx]
2022-11-12 Remove usage of the three side keys
    [Key layout.xlsx]
2022-11-13 WIP new PCB
    [pcb_v2.kicad_pcb, pcb_v2.kicad_sch]
2022-11-13 WIP second board
    [pcb_v2.kicad_pcb, pcb_v2.kicad_sch]
2022-11-14 move windows key
    [Key layout.xlsx]
2022-11-15 add pcb host pcb
    [pcb_host-CuBottom.gbr, pcb_host-CuTop.gbr, pcb_host-EdgeCuts.gbr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]
2022-11-15 update pcb for host
    [pcb_host-CuBottom.gbr, pcb_host-CuTop.gbr, pcb_host-EdgeCuts.gbr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]
2022-11-29 pcb v2 fixes + support for v2 in firmware
    [pcb_v2.kicad_pcb, pcb_v2.kicad_sch]
2023-01-10 Add 3d component models on PCB
    [pcb_v2.kicad_pcb]
2023-01-11 enclosure for v2
    [enclosure v2-back.stl, enclosure v2-front.stl]
2023-10-22 Revert "Merge branch 'multi-core' into main"
    This reverts commit 98082139902066240b697b9f0432adf0479ba885, reversing
    changes made to 2e37bbca62585b6878b8854fa4573379c4c96814.
    [arduino_keyboard.ino]
2025-02-23 Rework how "on release" keys are handled
    [arduino_keyboard.ino]
2025-02-27 Fix DEBUG_LOG compilation issues
    [arduino_keyboard.ino]
2025-02-27 Bugfix and disable overlap removal that is causing issues
    [arduino_keyboard.ino, input.cpp]
2025-02-28 Fix bugs for "on release" events
    [arduino_keyboard.ino]
2025-05-26 Add key to hold space and move "_"
    [Key layout.xlsx]
2025-07-29 Add media key controls
    [Key layout.xlsx]
2026-08-23 Treat a late release of a tap/layer key as a tap
    Space is both an "on release" key (tap emits space) and a layer key (hold
    selects the accent layer). When typing " a" quickly, space is often released
    just after the next key is pressed:
    press SPACE, press A, release SPACE, release A
    The "on release" code sees the press of A before the release of SPACE, so it
    declines the tap, activates the accent layer, and A comes out as an accented
    character instead of " a".
    The overlap removal block now detects that race and emits the tap itself, so
    the layer is never activated and the key pressed in between resolves on the
    base layer. Only the tap key's own press and release are removed from the
    qu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
    [arduino_keyboard.ino]
2026-09-21 Compact debugger timeline and combine HID output traces
    Fit the app to the viewport, display single-line input/output summaries, and record keyboard and media reports in one trace event.
2026-09-25 Disable overlap removal and document the "I'm" example
    Overlap removal turned a deliberate Space-hold + T (apostrophe) into a Space tap followed by 't', typing "I tm" instead of "I'm". Disable it for now and add examples.md with the traced key sequence a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
